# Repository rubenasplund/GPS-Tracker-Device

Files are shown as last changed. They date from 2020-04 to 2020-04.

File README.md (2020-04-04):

# GPS Tracker Device

## Project

The purpose for this project is to make a GPS tracker device which tracks position and movement patterns on animlas or things. Then sends the position data through lora.

## Areas of expertise

- Ruben will do the software
- Simon Will do the hardware

## Dependencies
- Install rust [https://rustup.rs/](https://rustup.rs/)

- Rust 1.40, or later

- `rustup update`

- `rustup target add thumbv7em-none-eabihf`

## Debug and Run

- `openocd -f openocd.cfg`

- `cargo run`

## Components

* GPS module - Adafruit 746 - https://www.elfa.se/en/mtk3339-gps-breakout-adafruit-746/p/30091220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

* Micro USB connector - https://www.elfa.se/en/micro-usb-with-solder-tabs-micro-usb-socket-right-angle-poles-molex-105017-0001/p/30161483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

* A display - SSD1306 SPI - https://cdon.se/hem-tradgard/oled-display-0-96-tum-vit-128x64-pixlar-ssd1306-spi-p50506639

* Temperature sensor - TMP36FSZ - https://se.rs-online.com/web/p/temperature-sensors-humidity-sensors/0412973/

* LED SMD 0805 - https://www.elfa.se/en/smd-led-640nm-0805-150mcd-20ma-kingbright-kp-2012surc/p/17531013?queryFromSuggest=true

* ADC - Integrated in MCU

* Battery (chargable) -ICP501022UPM - https://www.elfa.se/sv/litiumjonpolymerbatteripack-340mah-7v-renata-icp422339pr/p/30158712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

* Charging circuit (for battery)- MCP73831T-2ACI/OT https://www.elfa.se/sv/laddkrets-75-sot-23-microchip-mcp73831t-2aci-ot/p/17386933?track=true&no-cache=true

* Button - https://www.elfa.se/en/tactile-switch-b3fs-1no-47n-6mm-omron-electronic-components-b3fs-1012p/p/30156578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

* Power switch - https://www.elfa.se/en/low-power-slide-switch-1co-on-on-pcb-smd-rnd-components-rnd-210-00603/p/30152627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

* Regulator lm1117 ADJ - https://se.rs-online.com/web/p/low-dropout-voltage-regulators/8472888/

* Current limiter - RT9742EGJ5 - https://www.digikey.se/product-detail/en/richtek-usa-inc/RT9742EGJ5/1028-1432-2-ND/5880515

* Diode (prevents currents going wrong way) - https://www.elfa.se/en/schottky-diode-1a-40v-do-214ac-sma-vishay-ss14-e3-61t/p/30048133

* Coax connector - https://www.elfa.se/en/micro-coaxial-straight-socket-micro-coaxial-connector-50ohm-6ghz-molex-73412-0110/p/30076410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

* Pin connectors to display and the GPS module - https://www.elfa.se/en/straight-male-pcb-header-through-hole-rows-10-contacts-54mm-pitch-rnd-connect-rnd-205-00631/p/30093651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

* Pin connector to the battery - https://www.elfa.se/sv/kk-254-rak-hane-kretskortslist-genomgaende-hal-rader-kontakter-54mm-stiftavstand-molex-22-29-2021/p/30048774

* Pin female connector - https://www.elfa.se/en/straight-female-pcb-receptacle-through-hole-rows-10-contacts-54mm-pitch-rnd-connect-rnd-205-00650/p/30093670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

## Also needed for project

* Anti aliasing filters for sampling.

* Amplifiers to amplify eventually low signals to be measurable.

* ADC with at least 8 bits.

## TMP36FSZ

* Voltage range (100mV - 1750 mV)

* Temperature range -40 - 125 degrees

## Needed changes on pcb layout

* Add buttons on the MCU reset and also on the OLED reset, (alternatively connect them to the same reset button) 

## References

* https://github.com/mcci-catena/HW-Designs/blob/master/Boards/Catena-4610/234001131b_(Catena-4610-Schematic).pdf

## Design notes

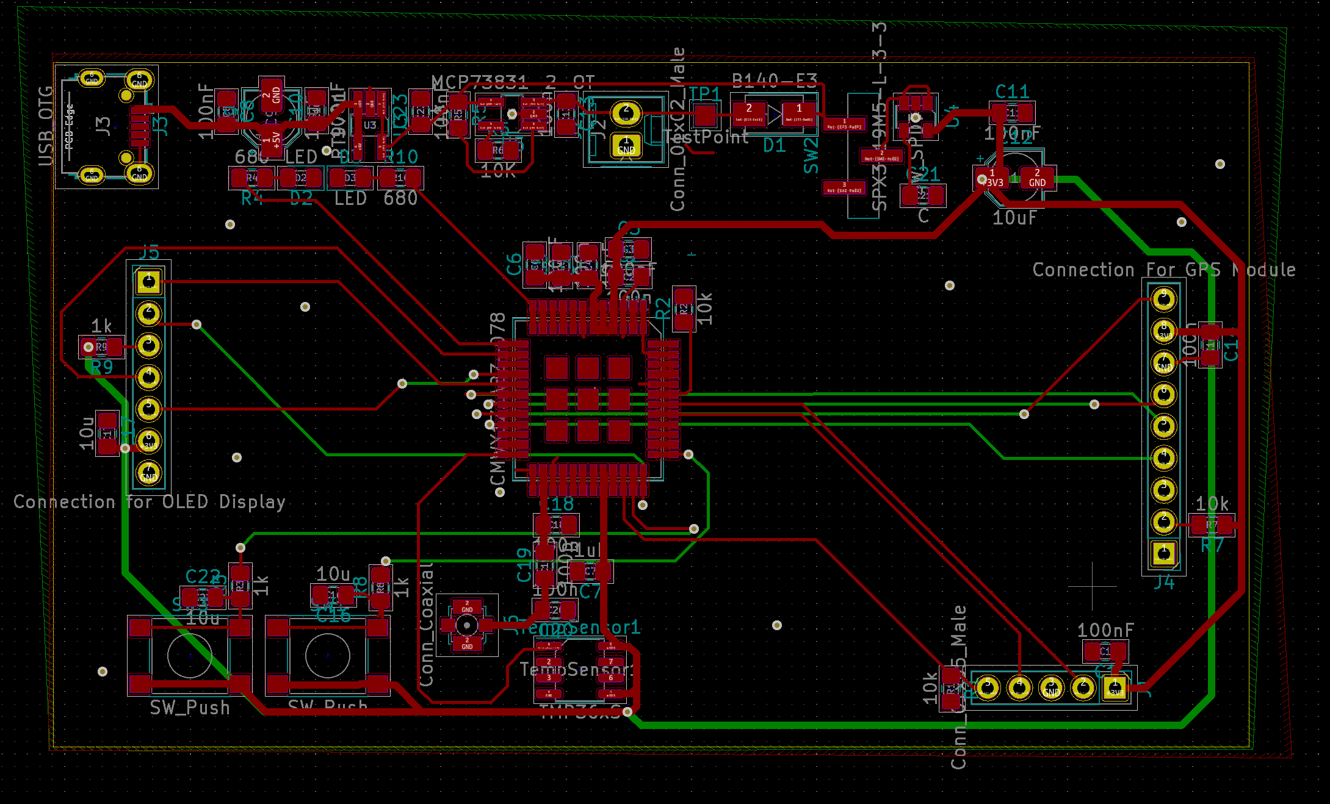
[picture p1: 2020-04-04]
Hardware/Images/Layout_image.PNG

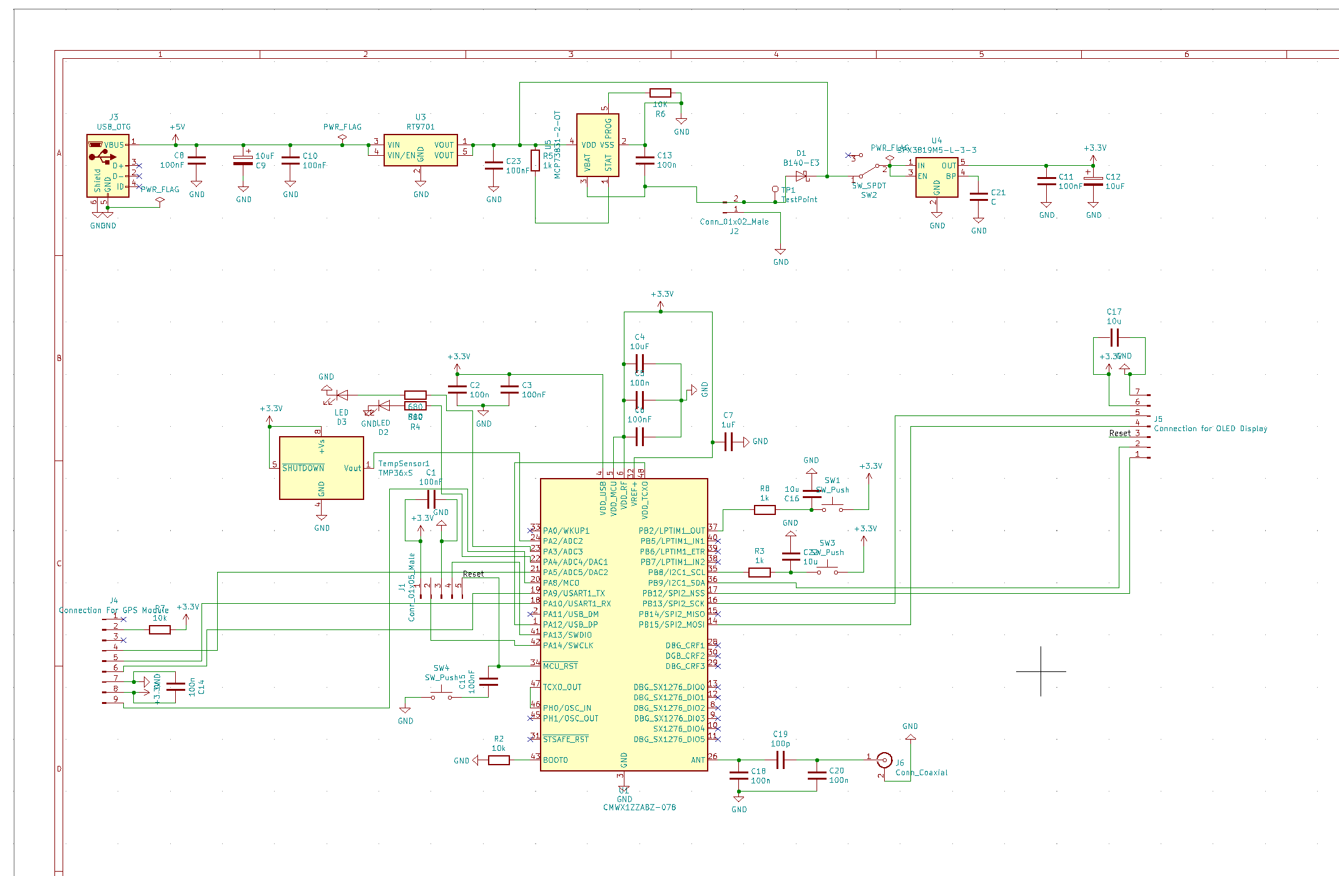
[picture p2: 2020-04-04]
Hardware/Images/schematic_image.PNG

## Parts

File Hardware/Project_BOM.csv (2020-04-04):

Id | Designator | Package | Quantity | Designation | Supplier and ref
1 | R10,R4 | R_0805_2012Metric_Pad1.15x1.40mm_HandSolder | 2 | 680
2 | C23,C1,C3,C6,C8,C10,C11 | C_0805_2012Metric_Pad1.15x1.40mm_HandSolder | 7 | 100nF
3 | D3,D2 | LED_0805_2012Metric_Pad1.15x1.40mm_HandSolder | 2 | LED
4 | SW3,SW1 | SW_Push_1P1T_NO_6x6mm_H9.5mm | 2 | SW_Push
5 | R3,R5,R8,R9 | R_0805_2012Metric_Pad1.15x1.40mm_HandSolder | 4 | 1k
6 | C22,C16,C17 | C_0805_2012Metric_Pad1.15x1.40mm_HandSolder | 3 | 10u
7 | C13,C14,C15,C18,C20,C2,C5 | C_0805_2012Metric_Pad1.15x1.40mm_HandSolder | 7 | 100n
8 | C19 | C_0805_2012Metric_Pad1.15x1.40mm_HandSolder | 1 | 100p
9 | C21 | C_0805_2012Metric_Pad1.15x1.40mm_HandSolder | 1 | C
10 | D1 | D_SMA | 1 | B140-E3
11 | J2 | Molex_KK-254_AE-6410-02A_1x02_P2.54mm_Vertical | 1 | Conn_01x02_Male
12 | J4 | PinHeader_1x09_P2.54mm_Vertical | 1 | Connection For GPS Module
13 | J5 | PinHeader_1x07_P2.54mm_Vertical | 1 | Connection for OLED Display
14 | J6 | U.FL_Molex_MCRF_73412-0110_Vertical | 1 | Conn_Coaxial
15 | R6 | R_0805_2012Metric_Pad1.15x1.40mm_HandSolder | 1 | 10K
16 | R7,R1,R2 | R_0805_2012Metric_Pad1.15x1.40mm_HandSolder | 3 | 10k
17 | SW2 | Power_Switch_cuuul | 1 | SW_SPDT
18 | TempSensor1 | SOIC-8_3.9x4.9mm_P1.27mm | 1 | TMP36xS
19 | TP1 | TestPoint_Pad_1.5x1.5mm | 1 | TestPoint
20 | U3 | TSOT-23-5_HandSoldering | 1 | RT9701
21 | U4 | SOT-23-5 | 1 | SPX3819M5-L-3-3
22 | U5 | TSOT-23-5_HandSoldering | 1 | MCP73831-2-OT
23 | C4 | C_0805_2012Metric_Pad1.15x1.40mm_HandSolder | 1 | 10uF
24 | C7 | C_0805_2012Metric_Pad1.15x1.40mm_HandSolder | 1 | 1uF
25 | C9,C12 | CP_Elec_4x4.5 | 2 | 10uF
26 | J1 | PinHeader_1x05_P2.54mm_Vertical | 1 | Conn_01x05_Male
27 | J3 | USB_Micro-B_Molex-105017-0001 | 1 | USB_OTG
28 | U1 | CMWX1ZZABZ_longer_padz | 1 | CMWX1ZZABZ-078

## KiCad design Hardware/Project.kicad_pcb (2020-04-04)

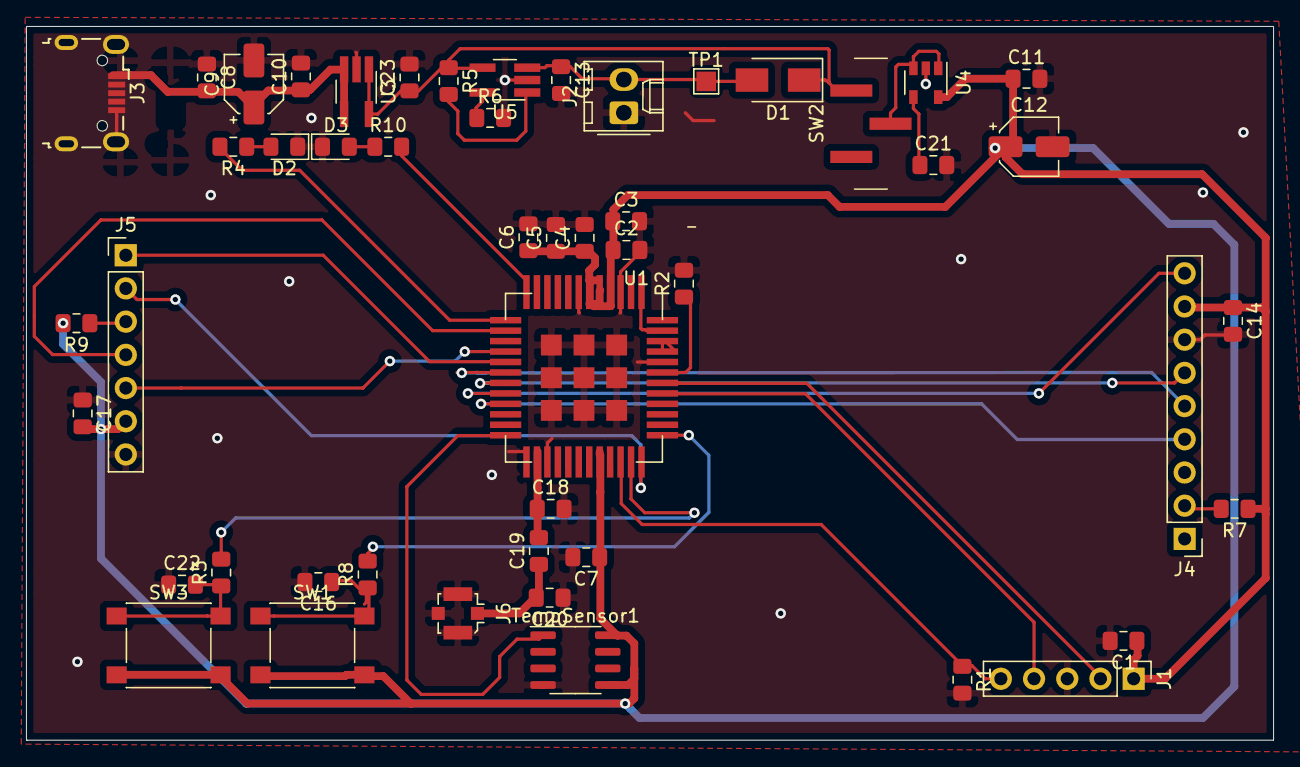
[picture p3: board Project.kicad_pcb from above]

Board: 2 copper layers, 95.4 x 54.6 mm, 50 parts (0 on the bottom side), 36 nets.

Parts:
C1, C3, C6, C8, C10, C11, C23: 100nF; C_0805_2012Metric_Pad1.15x1.40mm_HandSolder
C2, C5, C13, C14, C18, C20: 100n; C_0805_2012Metric_Pad1.15x1.40mm_HandSolder
C4: 10uF; C_0805_2012Metric_Pad1.15x1.40mm_HandSolder
C7: 1uF; C_0805_2012Metric_Pad1.15x1.40mm_HandSolder
C9, C12: 10uF; CP_Elec_4x4.5
C16, C17, C22: 10u; C_0805_2012Metric_Pad1.15x1.40mm_HandSolder
C19: 100p; C_0805_2012Metric_Pad1.15x1.40mm_HandSolder
C21: C; C_0805_2012Metric_Pad1.15x1.40mm_HandSolder
D1: B140-E3; D_SMA
D2, D3: LED; LED_0805_2012Metric_Pad1.15x1.40mm_HandSolder
J1: Conn_01x05_Male; PinHeader_1x05_P2.54mm_Vertical
J2: Conn_01x02_Male; Molex_KK-254_AE-6410-02A_1x02_P2.54mm_Vertical
J3: USB_OTG; USB_Micro-B_Wuerth_629105150521
J4: Connection For GPS Module; PinHeader_1x09_P2.54mm_Vertical
J5: Connection for OLED Display; PinHeader_1x07_P2.54mm_Vertical
J6: Conn_Coaxial; U.FL_Molex_MCRF_73412-0110_Vertical
R1, R2, R7: 10k; R_0805_2012Metric_Pad1.15x1.40mm_HandSolder
R3, R5, R8, R9: 1k; R_0805_2012Metric_Pad1.15x1.40mm_HandSolder
R4, R10: 680; R_0805_2012Metric_Pad1.15x1.40mm_HandSolder
R6: 10K; R_0805_2012Metric_Pad1.15x1.40mm_HandSolder
SW1, SW3: SW_Push; SW_Push_1P1T_NO_6x6mm_H9.5mm
SW2: SW_SPDT; Power_Switch_cuuul
TP1: TestPoint; TestPoint_Pad_1.5x1.5mm
TempSensor1: TMP36xS; SOIC-8_3.9x4.9mm_P1.27mm
U1: CMWX1ZZABZ-078; CMWX1ZZABZ_longer_padz
U3: RT9701; TSOT-23-5_HandSoldering
U4: SPX3819M5-L-3-3; SOT-23-5
U5: MCP73831-2-OT; TSOT-23-5_HandSoldering

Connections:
+3V3: C1.1, C2.1, C3.1, C4.1, C5.1, C6.1, C7.1, C11.1, C12.1, C14.1, C17.2, J1.1, J4.8, J5.6, R7.1, R9.2, SW1.2, SW3.2, TempSensor1.5, TempSensor1.8, U1.4, U1.5, U1.6, U1.32, U4.5
+5V: C8.2, C9.1, C10.1, J3.1, U3.3, U3.4
GND: C1.2, C2.2, C3.2, C4.2, C5.2, C6.2, C7.2, C8.1, C9.2, C10.2, C11.2, C12.2, C13.2, C14.2, C16.2, C17.1, C18.2, C20.1, C21.2, C22.1, C23.2, D2.1, D3.1, J1.3, J2.1, J3.5, J3.6, J4.7, J5.7, J6.2, R1.2, R2.2, R6.2, TempSensor1.4, U1.3, U1.7, U1.25, U1.27, U1.44, U1.49, U1.50, U1.51, U1.52, U1.53, U1.54, U1.55, U1.56, U1.57, U3.2, U4.2, U5.2
unnamed: C13.1, D1.2, J2.2, TP1.1, U5.3
unnamed: C16.1, R8.1, SW1.1
unnamed: C18.1, C19.2, U1.26
unnamed: C19.1, C20.2, J6.1
unnamed: C21.1, U4.4
unnamed: C22.2, R3.1, SW3.1
unnamed: C23.1, D1.1, R5.1, SW2.1, U3.1, U3.5, U5.4
unnamed: D2.2, R4.1
unnamed: D3.2, R10.1
unnamed: J1.2, U1.42
unnamed: J1.4, U1.41
unnamed: J1.5, R1.1, U1.34
unnamed: J4.2, R7.2
unnamed: J4.4, U1.21
unnamed: J4.5, U1.18
unnamed: J4.6, U1.19
unnamed: J4.9, U1.20
unnamed: J5.1, U1.17
unnamed: J5.2, U1.36
unnamed: J5.3, R9.1
unnamed: J5.4, U1.14
unnamed: J5.5, U1.16
unnamed: R2.1, U1.43
unnamed: R3.2, U1.35
unnamed: R4.2, U1.13
unnamed: R5.2, U5.1
unnamed: R6.1, U5.5
unnamed: R8.2, U1.37
unnamed: R10.2, U1.12
unnamed: SW2.2, U4.1, U4.3
unnamed: TempSensor1.1, U1.24
unnamed: U1.1, U1.47
unnamed: U1.45, U1.46

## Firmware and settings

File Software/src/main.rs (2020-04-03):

#![no_main]
#![no_std]
#![allow(deprecated)]

extern crate panic_semihosting;

use hal::{
    gpio::*,
    pac,
    prelude::*,
    rcc::Config,
    spi,
    syscfg,
    serial::{Config as serialConfig, Rx, Serial, Tx},
    stm32::{USART1},
    timer,
    adc,
    exti::TriggerEdge,
};

use nb::block;
use cortex_m::peripheral::syst::SystClkSource;
use stm32l0xx_hal as hal;
use cortex_m_semihosting::hprintln;

#[rtfm::app(device = stm32l0xx_hal::pac, monotonic = rtfm::cyccnt::CYCCNT, peripherals = true)]
const APP: () = {
    struct Resources {
        INT: pac::EXTI,
        TX: Tx<USART1>,
        RX: Rx<USART1>,
        LED: gpioa::PA0<Output<PushPull>>,
        ADC: adc::Adc,
        SIG: gpioa::PA2<Analog>,
        Button: gpiob::PB6<Input<PullUp>>,
        #[init(false)]
        LED_STATE: bool,
        #[init(false)]
        LED_LOCK: bool,

    }

    // init runs in an interrupt free section
    #[init]
    fn init(cx: init::Context) -> init::LateResources {
        // Configure the clock.
        let mut rcc = cx.device.RCC.freeze(Config::hsi16());
        let mut syscfg = syscfg::SYSCFG::new(cx.device.SYSCFG, &mut rcc);

        // Acquire the GPIOB peripheral. This also enables the clock for GPIOB in
        // the RCC register.
        let gpioa = cx.device.GPIOA.split(&mut rcc);
        let gpiob = cx.device.GPIOB.split(&mut rcc);
        let gpioc = cx.device.GPIOC.split(&mut rcc);

        let exti = cx.device.EXTI;

        // Configure tx and rx
        let mut tx = gpioa.pa9.into_push_pull_output();
        let mut rx = gpioa.pa10.into_pull_up_input();

        // Configure led
        let mut led = gpioa.pa0.into_push_pull_output();
        led.set_low().ok();

        // Configure button
        let mut button = gpiob.pb6.into_pull_up_input(); 

        let mut syst = cx.core.SYST;
        // configures the system timer to trigger a SysTick exception 
        syst.set_clock_source(SystClkSource::Core);
        // syst.set_reload(16_000_000); // period = 1s
        syst.set_reload(1_000_000); // period = 1/16 s
        syst.enable_counter();
        syst.enable_interrupt();


        exti.listen(
            &mut syscfg,
            button.port(),
            button.pin_number(),
            TriggerEdge::Rising,
        );

        // let mut core = cx.core;
        // let device = cx.device;
    
        // let rcc = device.RCC.constrain();
    
        // 16 MHz (default, all clocks)
        // let clocks = rcc.cfgr.freeze();
    
        // let gpioa = device.GPIOA.split();
    
        // let tx = gpioa.pa2.into_alternate_af7();
        // let rx = gpioa.pa3.into_alternate_af7();
    
        let serial = Serial::usart1(
            cx.device.USART1,
            (tx, rx),
            serialConfig::default().baudrate(9_600.bps()),
            &mut rcc,
            // clocks,
        ).unwrap();
    
        // Separate out the sender and receiver of the serial port
        let (tx, rx) = serial.split();

        let adc = cx.device.ADC.constrain(&mut rcc);
        let sig = gpioa.pa2.into_analog();

        // let sck = gpiob.pb13;
        // let miso = gpiob.pb14;
        // let mosi = gpiob.pb15;
        // let nss = gpiob.pb12.into_push_pull_output();
        // let dc = gpiob.pb9.into_push_pull_output();
        // //longfi_bindings::set_spi_nss(nss);

        // // Initialise the SPI peripheral.
        // let mut _spi = cx.device
        //     .SPI2
        //     .spi((sck, miso, mosi), spi::MODE_0, 1_000_000.hz(), &mut rcc);

        // let reset = gpiob.pb8.into_push_pull_output();
    
        // Late resources
        init::LateResources {
            INT: exti,
            TX: tx,
            RX: rx,
            LED: led,
            ADC: adc,
            SIG: sig,
            Button: button,
        }
    }
    
    // idle may be interrupted by other interrupts/tasks in the system
    #[idle(resources = [RX, TX])]
    fn idle(cx: idle::Context) -> ! {
        let rx = cx.resources.RX;
        let tx = cx.resources.TX;

        loop {
        
            match block!(rx.read()) {
                Ok(byte) => {
                    // hprintln!("Ok {:?}", byte).unwrap();
                    // tx.write(byte).unwrap();
                }
                
                Err(err) => {

                }
            }
        }
    }

    // led is flashing until, when 3.3V signal is going through the adc PA2 then it stops flashing
    #[task(binds = SysTick, priority = 3, resources = [LED, LED_STATE, LED_LOCK, ADC, SIG])]
    fn led_pwn_toggle(cx: led_pwn_toggle::Context) {
        let mut led = cx.resources.LED;
        let mut adc = cx.resources.ADC;
        let mut sig = cx.resources.SIG;
        let mut val: u16 = 0;

        if *cx.resources.LED_STATE && !*cx.resources.LED_LOCK {
            led.set_high().ok();
        } else {
            led.set_low().ok();
        }
        *cx.resources.LED_STATE = !*cx.resources.LED_STATE;

        val = adc.read(sig).unwrap();
        // hprintln!(" {:?}", val).unwrap();

        if val >= 350 {
            *cx.resources.LED_LOCK = false;
        } else {
            *cx.resources.LED_LOCK = true;
        }
    }

    #[task(priority = 5)]
    fn button_event(cx: button_event::Context) {
        hprintln!("button is pressed!!").unwrap();
    }

    #[task(binds = EXTI4_15, priority = 1, resources = [Button, INT], spawn = [button_event])]
    fn EXTI4_15(c: EXTI4_15::Context) {
        c.spawn.button_event().unwrap();
        c.resources.INT.clear_irq(c.resources.Button.pin_number());

    }

    // Interrupt handlers used to dispatch software tasks
    extern "C" {
        fn USART4_USART5();
    }
};

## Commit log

2020-02-10 update
    Added datasheet for current limiter
2020-02-11 Update
    Added coax connector to readme
2020-04-02 Added led pwm
2020-04-03 Added led toggle with adc signal
2020-04-03 Added button
2020-04-04 Added hardware
    [Lab_1-B_Adhes.gbr, Lab_1-B_CrtYd.gbr, Lab_1-B_Cu.gbr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]
